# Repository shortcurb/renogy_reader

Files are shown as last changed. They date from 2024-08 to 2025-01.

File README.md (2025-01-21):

Respectfully and appreciably forked from wrybread/ESP32ArduinoRenogy. There's no way I would have been able to figure out the Modbus on my own.

Like wrybread, I have an off-grid need for electricity, mostly because I want to try running a very small homelab in my backyard shed.
I have a Renogy Wanderer 30A charger and a Wanderer 10A charger (generally referenced as CC herein), if I haven't updated this README saying otherwise, they both support the software and hardware in this repo.

This repo contains both a through-hole PCB and an expanded aruidno sketch that reads the data from the CC and fires it off to an MQTT broker
# Hardware features:
* ESP32
* LM2596 through hole variant, from eBay/Amazon 4V-40V input, 5V, 3A output (make sure you set the potentiometer correctly!!)
* two DS18B20 temperature probes (one onboard, one via connector)
* Power connector
* Three connectors for offboard relays (either 5V or powered by the board's main input voltage)
* RJ45 (ethernet) header, its mechanically compatible with an RJ12 cord, which is what you'll need for the CC plug
    * This actually insn't true, as the RJ12 can get inserted wrong and have incorrect contacts. I soldered an ethernet cord to an RJ12 cord and am using that now.

If you want an unpopulated or pre-populated board, please reach out to me. JLCPCB sends me 5 for every order, and I only need 1.

# Software features:
There are multiple pieces of software here:
# renogy_reader_arduino
Reads data from the modbus and the custom PCB and fires it off to an MQTT broker

# renogy_mqtt_db_interface
Is intented to run as a container on a local server (such as a homelab), read data sent from the arduino over MQTT, and write it to a mariadb database

# ESP32ArduinoRenogy

This lets you read data from Renogy charge controllers via their RS232 port using an ESP32 or Arduino. 

Wanderer

The inspiration came when I needed to power a pump at a remote pond whenever there was sufficient power from a solar panel, and I was surprised to learn that the load switch on the Renogy controllers can't do that natively. The load switch is only designed to control lights at night. Silly. This lets me use the load switch to power whatever I want, but see the "Notes on the Load Switch" below for some notes on its limitations. And of course it lets me do whatever else I want with the data from the Renogy charge controller including using a relay, and gives me a dirt cheap way to read the battery voltage, panel voltage and load wattage from an ESP32 or Arduino.

So far I've only tested this with Renogy Wanderer 30A (CTRL-WND30-LI) and Wanderer 10A charge controllers, please post to the Issues section if you test on more and I'll add it to the list below. It *should* work with any Renogy charge controller that has an RS232 port, which I think is all of them since they want to sell their [bluetooth module](https://www.renogy.com/bt-2-bluetooth-module/) that works with the RS232 port.

Here's a pic of my installation:

installation

## Making the Cable

Here's an overall wiring diagram:

wiring diagram

You'll need make a cable to connect the controller to your ESP32 or Arduino. Start with an RJ12 cable, which is an old phone cable with 6 wires. Make sure it doesn't have only 4 wires, which is an RJ11 cable.

Here's the RJ12 jack on my cable, note how there's 6 wires (white, black, red, green, yellow, blue):

rj12 cable jack

I don't know how standard the wire colors are but those are the colors on mine. You need the first 3 wires from the left, which on mine are the white, black and red wire.

You'll also need a TTL to RS232 level adjuster. I used [this one](https://www.amazon.com/dp/B07BJJ3TZR) but there are lots of other options (google "max3232"):

level adjuster

If the listing goes away, it's the "NOYITO TTL to RS232 Module TTL RS232 Mutual Conversion Module", costs $7. See the wiring diagram above for instructions on connecting to it.

## Use

After connecting the cable and flashing your ESP or Arduino you should be seeing data from your charge controller in Serial Monitor:

serial monitor

Feel free to post to Issues if not.

## Notes on the Code

There's a struct that holds all the data from the charge controller. A look at the struct shows what data that is:

```
struct Controller_data {
  
  uint8_t battery_soc;               // percent
  float battery_voltage;             // volts
  float battery_charging_amps;       // amps
  uint8_t battery_temperature;       // celcius
  uint8_t controller_temperature;    // celcius
  float load_voltage;                // volts
  float load_amps;                   // amps
  uint8_t load_watts;                // watts
  float solar_panel_voltage;         // volts
  float solar_panel_amps;            // amps
  uint8_t solar_panel_watts;         // watts
  float min_battery_voltage_today;   // volts
  float max_battery_voltage_today;   // volts
  float max_charging_amps_today;     // amps
  float max_discharging_amps_today;  // amps
  uint8_t max_charge_watts_today;    // watts
  uint8_t max_discharge_watts_today; // watts
  uint8_t charge_amphours_today;     // amp hours
  uint8_t discharge_amphours_today;  // amp hours
  uint8_t charge_watthours_today;    // watt hours
  uint8_t discharge_watthours_today; // watt hours
  uint8_t controller_uptime_days;    // days
  uint8_t total_battery_overcharges; // count
  uint8_t total_battery_fullcharges; // count

  // convenience values
  float battery_temperatureF;        // fahrenheit
  float controller_temperatureF;     // fahrenheit
  float battery_charging_watts;      // watts. necessary? Does it ever differ from solar_panel_watts?
  long last_update_time;             // millis() of last update time
};
Controller_data renogy_data;
```

For example there's battery_soc (battery state of charge), the battery_voltage, the battery_charging_amps, etc. There's examples in the code of how to access them, but for example you get the battery voltage like this:

```
Serial.println( renogy_data.battery_voltage );
```

There's another struct that holds the info about the charge controller (it's voltage rating, amp rating, serial number, etc). I don't think all those are working yet. For example the serial number it reports is different than the one printed on my charge controller, which I think is just because of how my code processes the serial number data, but I don't need that functionality so I haven't fixed that yet. 

And note the commented out section in the code that turns the load switch on and off. For example this would turn the load on for 10 seconds:

```
renogy_control_load(1)
delay(10000);
renogy_control_load(0)
```

## Notes on the Load Switch

I think the load switch uses a MOSFET, which means anything with an inductive kickback (like a brush motor) might damage the switch or the unit itself. But I've been powering a bilge pump on it, which I think is an inductive load, for months without an issue. I'm willing to risk my cheapie PWM charge controller for that, but be careful what you power from the load switch directly. And of course you can connect a relay to the load switch to control anything else, or just connect a relay directly to your Arduino or ESP32.

Renogy is oddly uncommunicative about the limits of the load switch, and my theory is that that's because it's a bit complicated. My theory is that the capacity is shared between the battery input and the switch output. So for example if the 10 amp charge controller is pulling 8 amps of power from the solar panels, that leaves only 2 amps for the load switch. That would explain both why they don't mention the actual load limit, and why they only let us control the load at night (when the solar panels aren't competing for the capacity). But still, if that's the case, it would be nice for Renogy to mention that. And furthermore having options to control the load switch in the day would allow for someone to either have a larger controller than their panel so daytime power wouldn't be an issue, or to just use a relay connected to the load switch. Furthermore the manual says the controller will shut off the load switch and show an error code if the capacity reaches 105%, so maybe exceeding the load limit by a bit isn't catastrophic.

Anyway you can of course bypass all these issues by just controlling a relay directly from your ESP or Arduino.

For the record here's a screenshot from the Renogy Wanderer 10a manual showing the modes of the load switch:

load modes

Such an odd limitation to design them only to handle lights. Oh well, nothing an ESP32 or Arduino can't fix.

## General Notes

- as of now this is untested on an Arduino, I've only used it with ESP32's (both a Rover and a Wroom). It should work fine with an Arduino, the only thing I'm uncertain about is whether you can have two Serial interfaces with all Arduinos (and this script uses one Serial interface for communication with the Renogy controller and one to print status to the console). It should work fine though. If you test with an Arduino please post to this project's Issues section.

- I couldn't power the ESP32 directly from the charge controller, my theory is that it's so low power that the charge controller thinks nothing is connected and shuts off the USB port. Oh well, I used one of [these](https://www.amazon.com/gp/product/B08H89LTP5) 12v to 5v adaptors:

12v to 5v

## See Also

There's a couple of other projects that get data from the Renogy charge controllers. Oddly I couldn't find anything that uses an ESP32 or Arduino though.

- [here's a NodeJS project](https://github.com/mickwheelz/NodeRenogy)

- [here's a pure javascript project](https://github.com/menloparkinnovation/renogy-rover)

Much thanks to them! They made this much easier. 

Those are all for Raspberry Pi's or similar though. For my use case a Raspberry Pi is vastly overkill and has a lot of drawbacks: it needs to be shutdown properly, has a corruptible SD card, uses about 10 times the power of an Arduino or ESP (and an ESP32 can use deep sleep mode, which uses almost no power at all), has a super slow bootup time as opposed to instantly on, has an OS which needs to be kept up to date and is subject to lock ups, etc. ESP32's are in general much more robust in my experience. Once you get it working it just works, I'm betting for decades. That's not to say there aren't times where a Pi or similar makes more sense of course, but a remote solar installation probably isn't one of them.

I also attached Renogy's RS232/modbus manual, it's somewhat occaisonally helpful if you squint at it long enough.

## Tested On

So far it's been tested and confirmed working well on these controllers:

- Wanderer 30A (CTRL-WND30-LI)
- Wanderer 10A

It *should* work on any Renogy charge controller with an RS232 port. And most if not all of them have that port since Renogy wants to sell their [bluetooth module](https://www.renogy.com/bt-2-bluetooth-module/), which uses that port to get its data. This should also be pretty easy to adapt to other charge controllers that make their data available via modbus.
 
Please post to the Issues section if you test on other Renogy charge controllers, or email me (wrybread@gmail.com). 

## To Do

- I don't think it's correctly reading the serial number register, and possibly some of the other registers having to do with the model number. Please let me know if you figure out any fixes. (wrybread@gmail.com or post to Issues).

- would be nice to add Bluetooth support for monitoring from a phone, posting to MQTT brokers and pvwatts, etc.

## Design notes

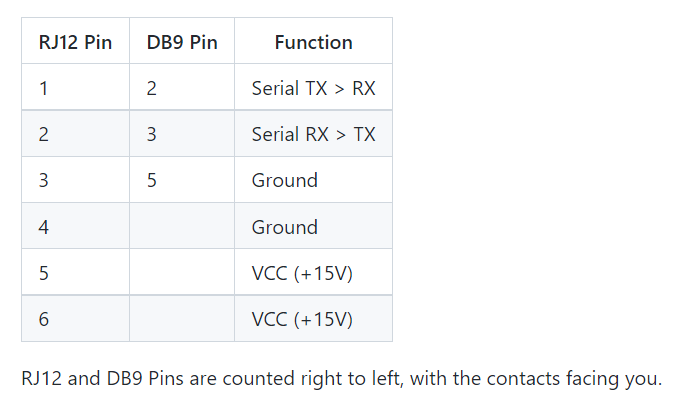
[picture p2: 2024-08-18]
references/5f45364e8110b863d892ca47645f56b64de6c801.png

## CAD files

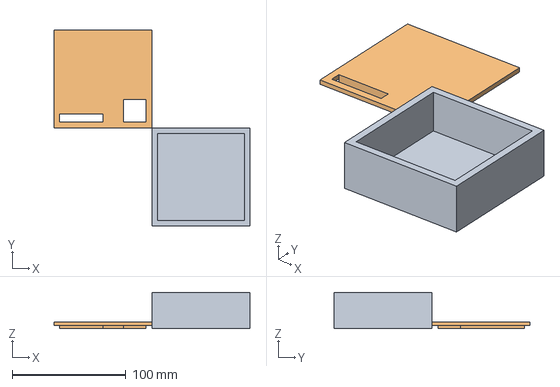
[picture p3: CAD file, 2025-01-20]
printed_case/renogy_reader_case.FCStd
172.0 x 172.0 x 32.0 mm
Container
Lid

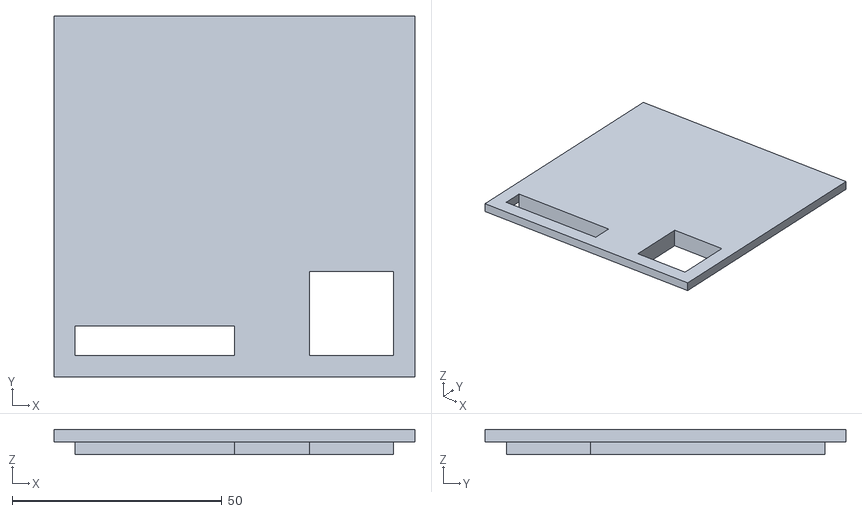
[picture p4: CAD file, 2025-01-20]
printed_case/lid.stl
86.0 x 86.0 x 6.00

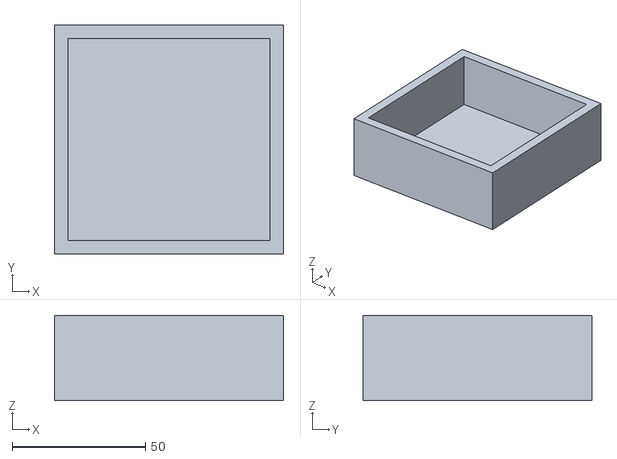
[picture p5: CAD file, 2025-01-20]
printed_case/container.stl
86.0 x 86.0 x 32.0

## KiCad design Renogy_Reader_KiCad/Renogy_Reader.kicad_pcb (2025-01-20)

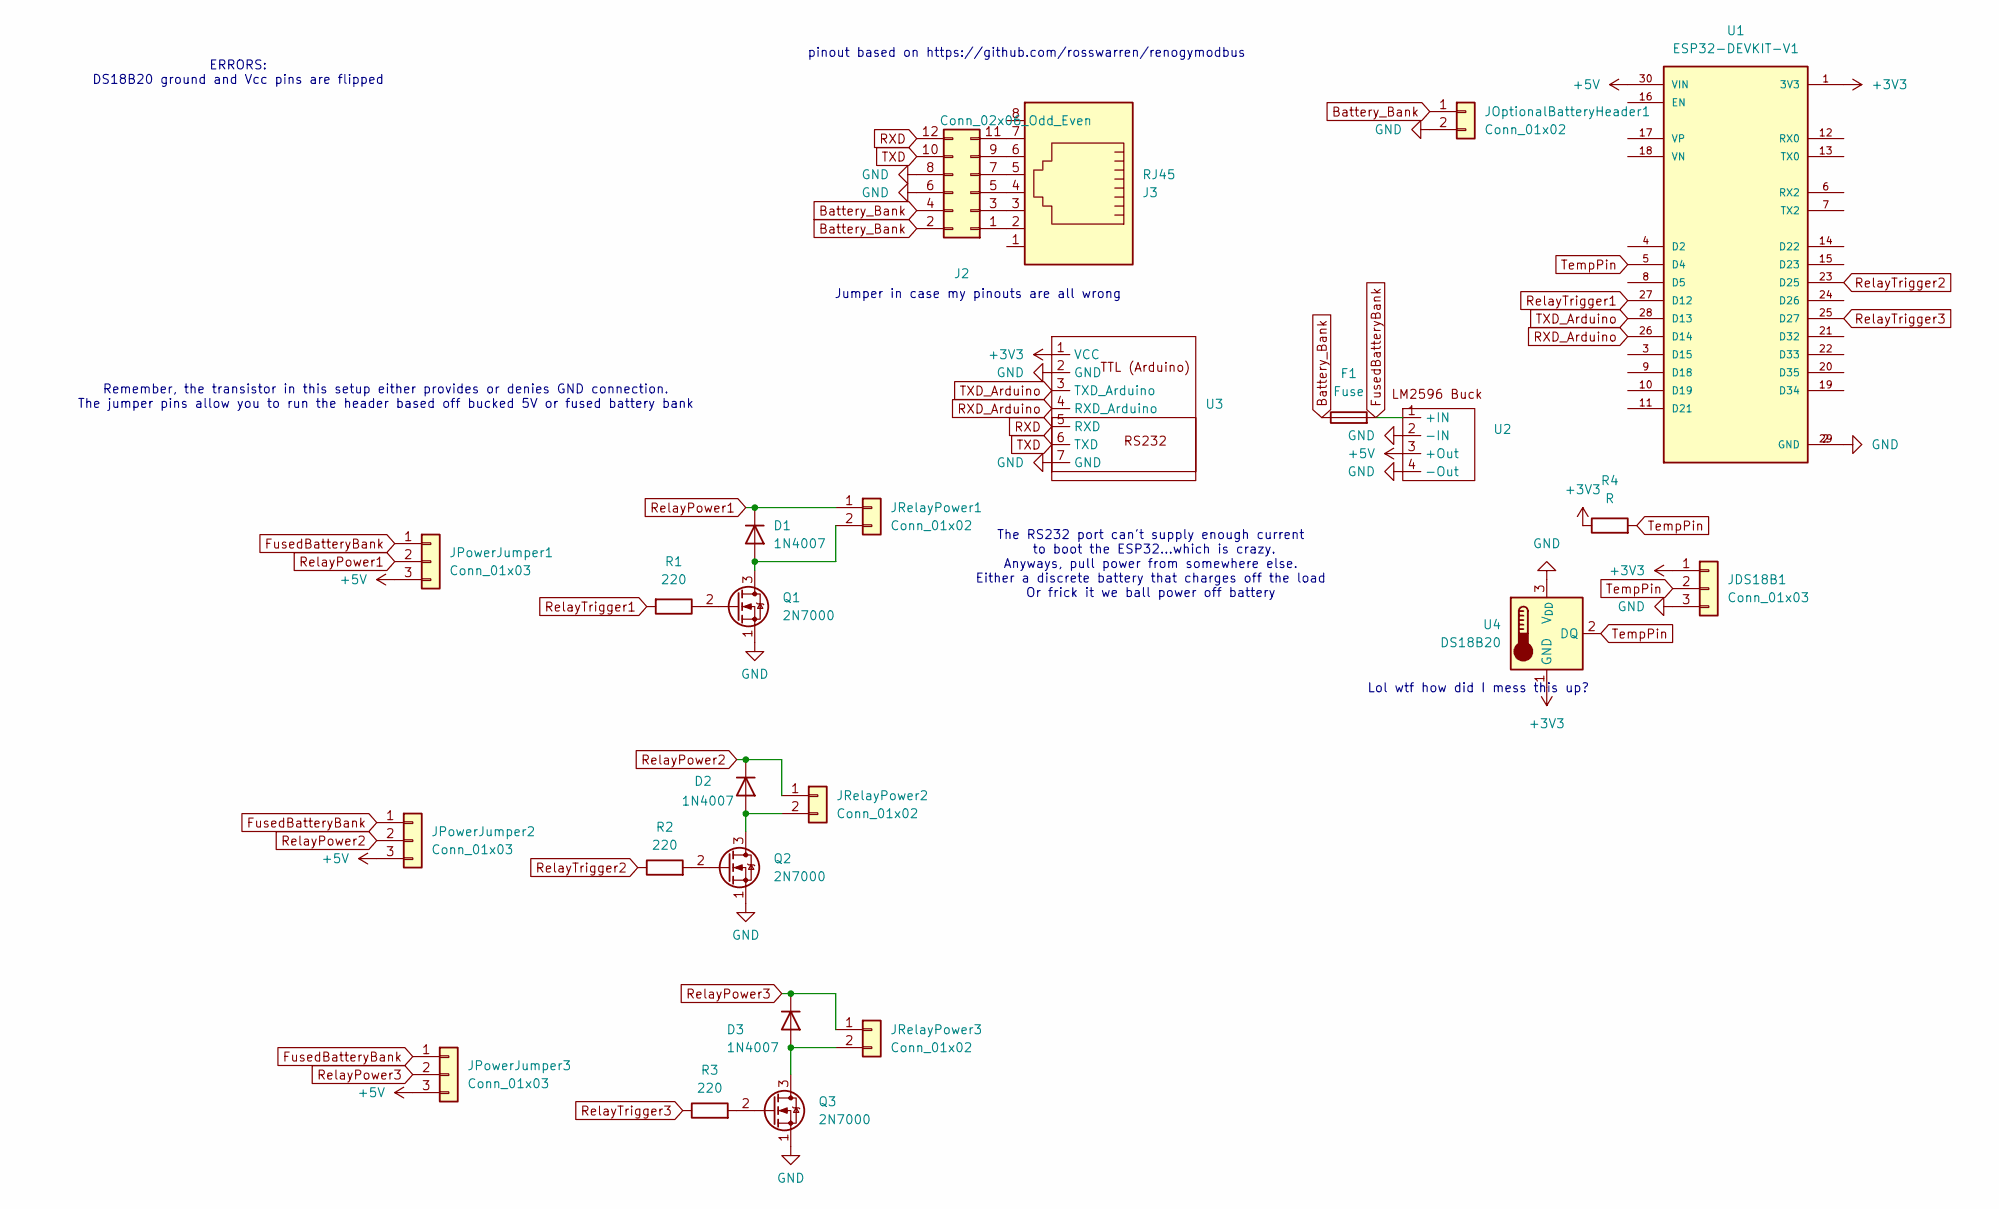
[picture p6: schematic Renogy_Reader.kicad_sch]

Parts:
D1, D2, D3: 1N4007; D_DO-41_SOD81_P10.16mm_Horizontal
F1: Fuse; Fuseholder_Clip-5x20mm_Keystone_3512P_Inline_P23.62x7.27mm_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
J2: Conn_02x06_Odd_Even; PinHeader_2x06_P2.54mm_Vertical
J3: RJ45; RJ45_Amphenol_54602-x08_Horizontal
JDS18B1: Conn_01x03; JST_EH_B3B-EH-A_1x03_P2.50mm_Vertical
JOptionalBatteryHeader1: Conn_01x02; JST_EH_B2B-EH-A_1x02_P2.50mm_Vertical
JPowerJumper1, JPowerJumper2, JPowerJumper3: Conn_01x03; JST_EH_B3B-EH-A_1x03_P2.50mm_Vertical
JRelayPower1, JRelayPower2, JRelayPower3: Conn_01x02; JST_EH_B2B-EH-A_1x02_P2.50mm_Vertical
Q1, Q2, Q3: 2N7000; TO-92_Inline
R1, R2, R3: 220; R_Axial_DIN0411_L9.9mm_D3.6mm_P12.70mm_Horizontal
R4: R; R_Axial_DIN0411_L9.9mm_D3.6mm_P12.70mm_Horizontal
U1: ESP32-DEVKIT-V1; MODULE_ESP32_DEVKIT_V1; PARTREV N/A
U2: LM2596-AE
U3: TTL-RS232 Converter
U4: DS18B20; TO-92_Inline

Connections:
+3V3: JDS18B1.1, R4.1, U1.1 (3V3), U3.1 (VCC), U4.1 (GND)
+5V: JPowerJumper1.3, JPowerJumper2.3, JPowerJumper3.3, U1.30 (VIN), U2.3 (+Out)
Battery_Bank: F1.1, J2.2, J2.4, JOptionalBatteryHeader1.1
FusedBatteryBank: F1.2, JPowerJumper1.1, JPowerJumper2.1, JPowerJumper3.1, U2.1 (+IN)
GND: J2.6, J2.8, JDS18B1.3, JOptionalBatteryHeader1.2, Q1.1 (S), Q2.1 (S), Q3.1 (S), U1.2 (GND), U1.29 (GND), U2.2 (-IN), U2.4 (-Out), U3.2 (GND), U3.7 (GND), U4.3 (V_{DD})
unnamed: D1.2 (A), JRelayPower1.2, Q1.3 (D)
unnamed: D2.2 (A), JRelayPower2.2, Q2.3 (D)
unnamed: D3.2 (A), JRelayPower3.2, Q3.3 (D)
unnamed: J2.1, J3.2
unnamed: J2.3, J3.3
unnamed: J2.5, J3.4
unnamed: J2.7, J3.5
unnamed: J2.9, J3.6
unnamed: J2.11, J3.7
unnamed: Q1.2 (G), R1.1
unnamed: Q2.2 (G), R2.2
unnamed: Q3.2 (G), R3.2
RXD: J2.12, U3.5 (RXD)
RXD_Arduino: U1.26 (D14), U3.4 (RXD_Arduino)
RelayPower1: D1.1 (K), JPowerJumper1.2, JRelayPower1.1
RelayPower2: D2.1 (K), JPowerJumper2.2, JRelayPower2.1
RelayPower3: D3.1 (K), JPowerJumper3.2, JRelayPower3.1
RelayTrigger1: R1.2, U1.27 (D12)
RelayTrigger2: R2.1, U1.23 (D25)
RelayTrigger3: R3.1, U1.25 (D27)
TXD: J2.10, U3.6 (TXD)
TXD_Arduino: U1.28 (D13), U3.3 (TXD_Arduino)
TempPin: JDS18B1.2, R4.2, U1.5 (D4), U4.2 (DQ)

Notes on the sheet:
Lol wtf how did I mess this up?
The RS232 port can't supply enough current to boot the ESP32...which is crazy. Anyways, pull power from somewhere else. Either a discrete battery that charges off the load Or frick it we ball power off battery
Remember, the transistor in this setup either provides or denies GND connection. The jumper pins allow you to run the header based off bucked 5V or fused battery bank
Jumper in case my pinouts are all wrong
ERRORS: DS18B20 ground and Vcc pins are flipped
pinout based on https://github.com/rosswarren/renogymodbus

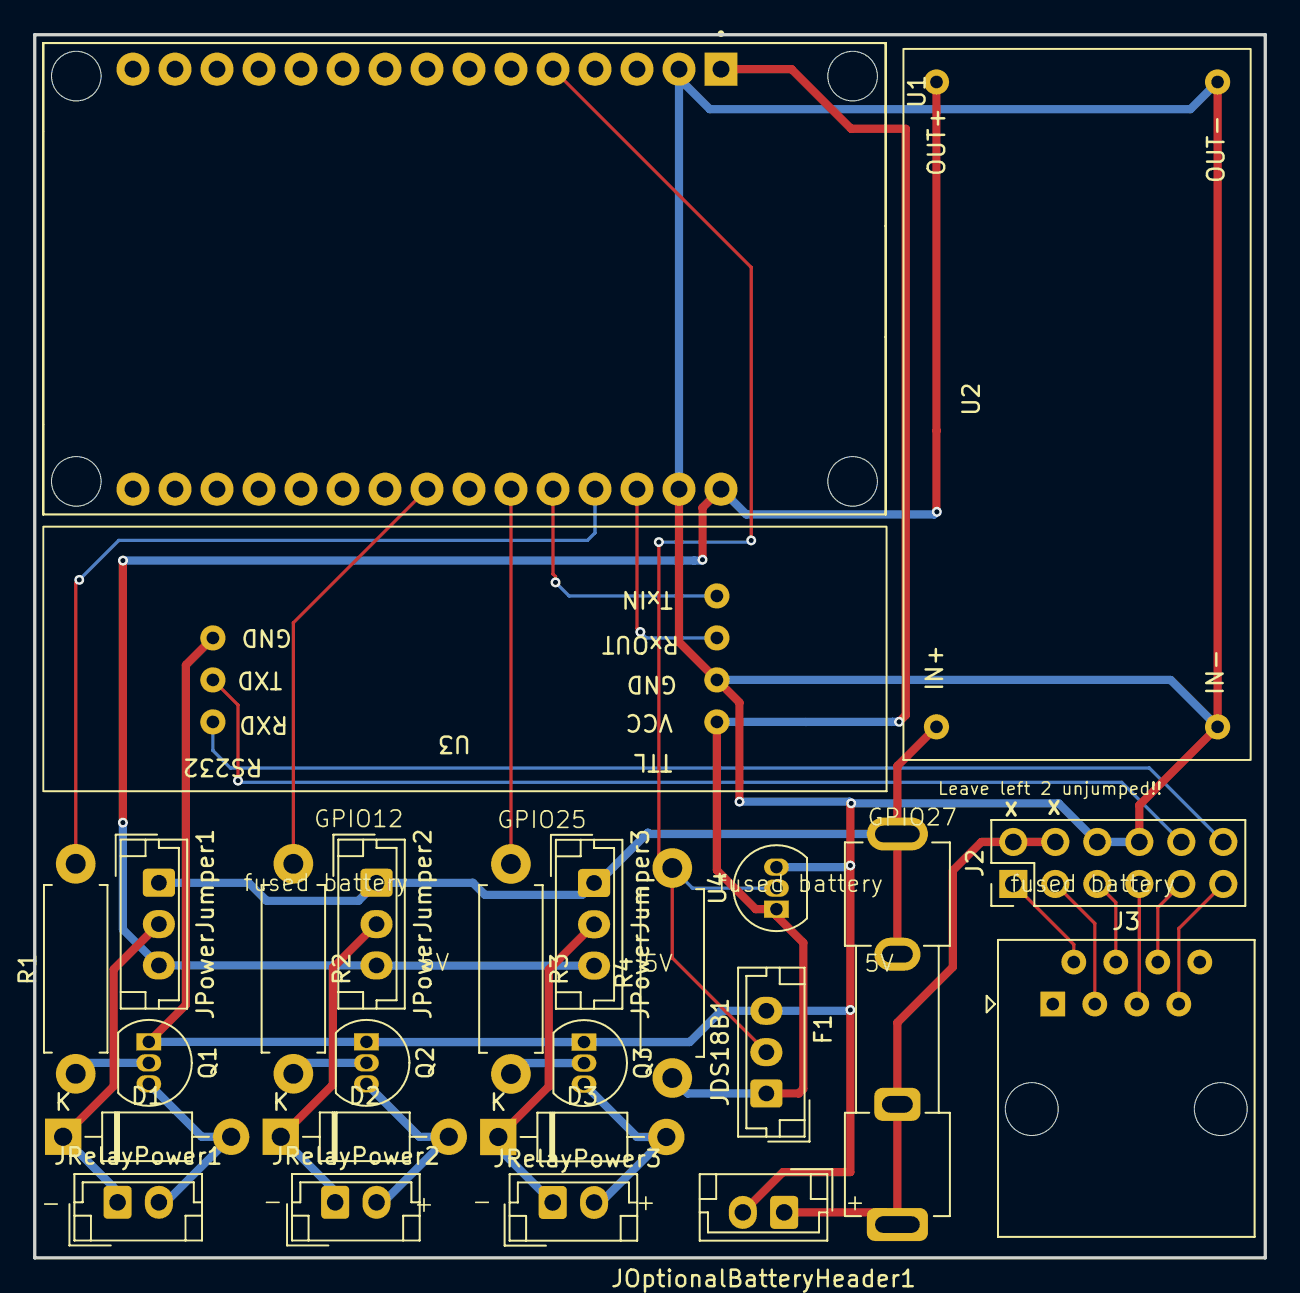
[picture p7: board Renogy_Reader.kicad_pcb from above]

Board: 2 copper layers, 74.4 x 74.0 mm, 25 parts (0 on the bottom side), 28 nets.

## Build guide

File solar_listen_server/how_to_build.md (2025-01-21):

sudo docker build -t solar-listen .
sudo docker run --env-file docker.env --name solar-listen -d solar-listen
The open portainer, switch the new container's network to bombur_default, and it'll run

If you get "key not found" errors, it just means that the ESP32 is sending MQTTs
that solar_listen.py doesn't know whether to treat as a string or a float. 
Make an entry in         self.data_structure = { if you want the error to go away

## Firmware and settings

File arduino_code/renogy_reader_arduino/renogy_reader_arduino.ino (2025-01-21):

// https://github.com/wrybread/ESP32ArduinoRenogy
// https://github.com/syvic/ModbusMaster
#include <ModbusMaster.h>
#include "secrets.h"
#include <WiFi.h>
#include <PubSubClient.h>
#include <ArduinoJson.h>  // Include ArduinoJson library
#include "esp_task_wdt.h" // Watchdog timer
#include <OneWire.h>
#include <DallasTemperature.h>

ModbusMaster node;

const int relaypin1 = 12;  // Relay 1 connected to D12
const int relaypin2 = 25;  // Relay 2 connected to D25
const int relaypin3 = 27;  // Relay 3 connected to D27 

#define RXD2 13
#define TXD2 14
#define ONE_WIRE_BUS 4  // GPIO D4 on ESP32

OneWire oneWire(ONE_WIRE_BUS);
DallasTemperature sensors(&oneWire);

const uint32_t num_data_registers = 35;
const uint32_t num_info_registers = 17;

bool simulator_mode = false;

WiFiClient espClient;
PubSubClient client(espClient);
const char* commandtopic = "kili/sagehouse/solar/renogy20/command";
int modbus_timeout_count = 0;  // Count consecutive Modbus timeouts
const int max_modbus_timeout_count = 5;  // Reset if this threshold is exceeded

struct Controller_data {
  
  uint8_t battery_soc;               // percent
  float battery_voltage;             // volts
  float battery_charging_amps;       // amps
  int16_t battery_temperature;       // celcius
  int16_t controller_temperature;    // celcius
  float load_voltage;                // volts
  float load_amps;                   // amps
  uint8_t load_watts;                // watts
  float solar_panel_voltage;         // volts
  float solar_panel_amps;            // amps
  uint8_t solar_panel_watts;         // watts
  float min_battery_voltage_today;   // volts
  float max_battery_voltage_today;   // volts
  float max_charging_amps_today;     // amps
  float max_discharging_amps_today;  // amps
  uint8_t max_charge_watts_today;    // watts
  uint8_t max_discharge_watts_today; // watts
  uint8_t charge_amphours_today;     // amp hours
  uint8_t discharge_amphours_today;  // amp hours
  uint8_t charge_watthours_today;    // watt hours
  uint8_t discharge_watthours_today; // watt hours
  uint8_t controller_uptime_days;    // days
  uint8_t total_battery_overcharges; // count
  uint8_t total_battery_fullcharges; // count
  uint16_t raw_data;

  // convenience values
  float battery_temperatureF;        // fahrenheit
  float controller_temperatureF;     // fahrenheit
  float battery_charging_watts;      // watts. necessary? Does it ever differ from solar_panel_watts?
  long last_update_time;             // millis() of last update time
  bool controller_connected;         // bool if we successfully read data from the controller
  float ds18tempC;
  float ds18tempF;
};
Controller_data renogy_data;

struct Controller_info {
  
  uint8_t voltage_rating;            // volts
  uint8_t amp_rating;                // amps
  uint8_t discharge_amp_rating;      // amps
  uint8_t type;
  uint8_t controller_name;
  char software_version[40];
  char hardware_version[40];
  char serial_number[40];
  uint8_t modbus_address;  

  float wattage_rating;
  long last_update_time;           // millis() of last update time
};
Controller_info renogy_info;

struct Relay_info {
    int relay1state;
    int relay2state;
    int relay3state;
    int loadstate;
};
Relay_info relay_info;

struct Board_info {
    float boardTempC;
    float boardTempF;
};
Board_info board_info;

void callback(char* topic, byte* message, unsigned int length) {
  Serial.print("Message arrived on topic: ");
  Serial.print(topic);
  Serial.print(". Message: ");
  String messageTemp;

  for (int i = 0; i < length; i++) {
    Serial.print((char)message[i]);
    messageTemp += (char)message[i];
  }
  Serial.println();

  // Handle the message received
  if (String(topic) == commandtopic) {
    handle_command(messageTemp);

  }
}

// control the load pins on Renogy charge controllers that have them
void renogy_control_load(bool state) {
    if (state==1) {
        Serial.println("Turning load on");
        node.writeSingleRegister(0x010A, 1);  // turn on load
    }
    else {
        Serial.println("Turning load off");
        node.writeSingleRegister(0x010A, 0);  // turn off load
    }
}

void reconnect() {
    while (!client.connected()) {
        Serial.print("Attempting MQTT connection...");
        if (WiFi.status() != WL_CONNECTED) { // Check Wi-Fi status first
            setup_wifi();
        }
        if (client.connect("ESP32Client", mqtt_user, mqtt_password)) {
            Serial.println("connected");
            client.subscribe(commandtopic);
        } else {
            Serial.print("failed, rc=");
            Serial.print(client.state());
            Serial.println(" try again in 5 seconds");
            delay(5000);
        }
    }
}

void setup_wifi() {
    delay(10);
    Serial.print("Connecting to ");
    WiFi.begin(ssid, password);
    while (WiFi.status() != WL_CONNECTED) {
        delay(500);
        Serial.print(".");
    }
    Serial.println("WiFi connected");
    Serial.println("IP address: ");
    Serial.println(WiFi.localIP());
}

void handle_command(const String message) {
    pinMode(relaypin1, OUTPUT);
    pinMode(relaypin2, OUTPUT);
    pinMode(relaypin3, OUTPUT);

    // Debug print
    Serial.println("Handling message: " + message);

    // Matching commands to control relays
    if (message == "relay1 on") {
        digitalWrite(relaypin1, HIGH);
    } else if (message == "relay1 off") {
        digitalWrite(relaypin1, LOW);
    } else if (message == "relay2 on") {
        digitalWrite(relaypin2, HIGH);
    } else if (message == "relay2 off") {
        digitalWrite(relaypin2, LOW);
    } else if (message == "relay3 on") {
        digitalWrite(relaypin3, HIGH);
    } else if (message == "relay3 off") {
        digitalWrite(relaypin3, LOW);
    } else if (message == "load on") {
        renogy_control_load(1);
    } else if (message == "load off") {
        renogy_control_load(0);
    } else {
        Serial.println("Unknown command: " + message);
    }
}

void setup() {
    Serial.begin(115200);
    Serial.println("Started!");

    // Configure and initialize the Task Watchdog Timer (WDT)
    static bool wdt_initialized = false;
    if (!wdt_initialized) {
        esp_task_wdt_config_t wdt_config = {
            .timeout_ms = 10000,       // Set WDT timeout to 10,000 ms
            .trigger_panic = true      // Trigger panic on timeout
        };
        esp_task_wdt_init(&wdt_config); // Initialize WDT with the config
        esp_task_wdt_add(NULL);         // Add current task to the watchdog
        wdt_initialized = true;         // Mark as initialized to avoid reinitializing
    }

    Serial2.begin(9600, SERIAL_8N1, RXD2, TXD2); 
    int modbus_address = 255; 
    node.begin(modbus_address, Serial2); 

    setup_wifi();
    client.setServer(mqtt_server, mqtt_port);
    client.setCallback(callback);
    sensors.begin();

    delay(100);
}

void loop() {
    esp_task_wdt_reset();  // Initial reset at the start of loop

    if (WiFi.status() != WL_CONNECTED) {  // Check Wi-Fi connection
        setup_wifi();
        esp_task_wdt_reset();  // Reset after Wi-Fi reconnection attempt
    }

    if (!client.connected()) {
        reconnect();
        esp_task_wdt_reset();  // Reset after MQTT reconnection attempt
    }

    client.loop();
    esp_task_wdt_reset();  // Reset after processing client.loop()

    static uint32_t lastTaskTime = 0;  
    const uint32_t TASK_INTERVAL = 5000;  // 5-second interval

    if (millis() - lastTaskTime >= TASK_INTERVAL) {
        lastTaskTime = millis();
        send_data();           // Publish data and perform tasks
        esp_task_wdt_reset();  // Reset watchdog timer after successful task
    }

    delay(10);  // Small delay to prevent a tight loop; adjust if needed
}

void send_data() {
    static uint32_t i;
    i++;

    // set word 0 of TX buffer to least-significant word of counter (bits 15..0)
    node.setTransmitBuffer(0, lowWord(i));  
    // set word 1 of TX buffer to most-significant word of counter (bits 31..16)
    node.setTransmitBuffer(1, highWord(i));

    if (renogy_read_data_registers() && renogy_read_info_registers()) {
        read_relay_state();
        read_ds18b20();
        modbus_timeout_count = 0;  // Reset timeout count on successful read

        client.publish("kili/sagehouse/solar/renogy20/raw_data", String(renogy_data.raw_data).c_str());
        client.publish("kili/sagehouse/solar/renogy20/board_temperature", String(board_info.boardTempC).c_str());
        client.publish("kili/sagehouse/solar/renogy20/board_temperatureF", String(board_info.boardTempF).c_str());
        client.publish("kili/sagehouse/solar/renogy20/status", "Charge controller connected");
        client.publish("kili/sagehouse/solar/renogy20/battery_soc", String(renogy_data.battery_soc).c_str());
        client.publish("kili/sagehouse/solar/renogy20/battery_voltage", String(renogy_data.battery_voltage).c_str());
        client.publish("kili/sagehouse/solar/renogy20/battery_charging_amps", String(renogy_data.battery_charging_amps/10).c_str());
        client.publish("kili/sagehouse/solar/renogy20/battery_temperature", String(renogy_data.battery_temperature).c_str());
        client.publish("kili/sagehouse/solar/renogy20/controller_temperature", String(renogy_data.controller_temperature).c_str());
        client.publish("kili/sagehouse/solar/renogy20/load_voltage", String(renogy_data.load_voltage).c_str());
        client.publish("kili/sagehouse/solar/renogy20/load_amps", String(renogy_data.load_amps).c_str());
        client.publish("kili/sagehouse/solar/renogy20/load_watts", String(renogy_data.load_watts).c_str());
        client.publish("kili/sagehouse/solar/renogy20/solar_panel_voltage", String(renogy_data.solar_panel_voltage).c_str());
        client.publish("kili/sagehouse/solar/renogy20/solar_panel_amps", String(renogy_data.solar_panel_amps).c_str());
        client.publish("kili/sagehouse/solar/renogy20/solar_panel_watts", String(renogy_data.solar_panel_watts).c_str());
        client.publish("kili/sagehouse/solar/renogy20/min_battery_voltage_today", String(renogy_data.min_battery_voltage_today).c_str());
        client.publish("kili/sagehouse/solar/renogy20/max_battery_voltage_today", String(renogy_data.max_battery_voltage_today).c_str());
        client.publish("kili/sagehouse/solar/renogy20/max_charging_amps_today", String(renogy_data.max_charging_amps_today).c_str());
        client.publish("kili/sagehouse/solar/renogy20/max_discharging_amps_today", String(renogy_data.max_discharging_amps_today).c_str());
        client.publish("kili/sagehouse/solar/renogy20/max_charge_watts_today", String(renogy_data.max_charge_watts_today).c_str());
        client.publish("kili/sagehouse/solar/renogy20/max_discharge_watts_today", String(renogy_data.max_discharge_watts_today).c_str());
        client.publish("kili/sagehouse/solar/renogy20/charge_amphours_today", String(renogy_data.charge_amphours_today).c_str());
        client.publish("kili/sagehouse/solar/renogy20/discharge_amphours_today", String(renogy_data.discharge_amphours_today).c_str());
        client.publish("kili/sagehouse/solar/renogy20/charge_watthours_today", String(renogy_data.charge_watthours_today).c_str());
        client.publish("kili/sagehouse/solar/renogy20/discharge_watthours_today", String(renogy_data.discharge_watthours_today).c_str());
        client.publish("kili/sagehouse/solar/renogy20/controller_uptime_days", String(renogy_data.controller_uptime_days).c_str());
        client.publish("kili/sagehouse/solar/renogy20/total_battery_overcharges", String(renogy_data.total_battery_overcharges).c_str());
        client.publish("kili/sagehouse/solar/renogy20/total_battery_fullcharges", String(renogy_data.total_battery_fullcharges).c_str());
        client.publish("kili/sagehouse/solar/renogy20/battery_temperatureF", String(renogy_data.battery_temperatureF).c_str());
        client.publish("kili/sagehouse/solar/renogy20/controller_temperatureF", String(renogy_data.controller_temperatureF).c_str());
        client.publish("kili/sagehouse/solar/renogy20/battery_charging_watts", String(renogy_data.battery_charging_watts/10).c_str());
        client.publish("kili/sagehouse/solar/renogy20/last_update_time", String(renogy_data.last_update_time).c_str());
        client.publish("kili/sagehouse/solar/renogy20/controller_connected", renogy_data.controller_connected ? "true" : "false");

        client.publish("kili/sagehouse/solar/renogy20/voltage_rating", String(renogy_info.voltage_rating).c_str());
        client.publish("kili/sagehouse/solar/renogy20/amp_rating", String(renogy_info.amp_rating).c_str());
        client.publish("kili/sagehouse/solar/renogy20/discharge_amp_rating", String(renogy_info.discharge_amp_rating).c_str());
        client.publish("kili/sagehouse/solar/renogy20/type", String(renogy_info.type).c_str());
        client.publish("kili/sagehouse/solar/renogy20/controller_name", String(renogy_info.controller_name).c_str());
        client.publish("kili/sagehouse/solar/renogy20/software_version", renogy_info.software_version);
        client.publish("kili/sagehouse/solar/renogy20/hardware_version", renogy_info.hardware_version);
        client.publish("kili/sagehouse/solar/renogy20/serial_number", renogy_info.serial_number);
        client.publish("kili/sagehouse/solar/renogy20/modbus_address", String(renogy_info.modbus_address).c_str());
        client.publish("kili/sagehouse/solar/renogy20/wattage_rating", String(renogy_info.wattage_rating).c_str());
        client.publish("kili/sagehouse/solar/renogy20/last_update_time", String(renogy_info.last_update_time).c_str());

        client.publish("kili/sagehouse/solar/renogy20/relay1state", String(relay_info.relay1state).c_str());
        client.publish("kili/sagehouse/solar/renogy20/relay2state", String(relay_info.relay2state).c_str());
        client.publish("kili/sagehouse/solar/renogy20/relay3state", String(relay_info.relay3state).c_str());
        client.publish("kili/sagehouse/solar/renogy20/loadstate", String(relay_info.loadstate).c_str());


        esp_task_wdt_reset();  // Reset WDT after publishing data

    } else {
        client.publish("kili/sagehouse/solar/renogy20/status", "Charge controller disconnected");
        modbus_timeout_count++;
        if (modbus_timeout_count >= max_modbus_timeout_count) {
            esp_task_wdt_reset();  // Reset WDT after publishing data
            ESP.restart();  // Restart if too many consecutive timeouts
        }

    }
}

bool renogy_read_data_registers() {
  uint8_t j, result;
  uint16_t data_registers[num_data_registers];
  char buffer1[40], buffer2[40];
  uint16_t raw_data;

  // Prints data about each read to the console
  bool print_data = false;

  result = node.readHoldingRegisters(0x100, num_data_registers);
  if (result == node.ku8MBSuccess) {
    if (print_data) Serial.println("Successfully read the data registers!");
    renogy_data.controller_connected = true;

    for (j = 0; j < num_data_registers; j++) {
      data_registers[j] = node.getResponseBuffer(j);
      if (print_data) Serial.println(data_registers[j]);
    }

    renogy_data.battery_soc = data_registers[0];
    renogy_data.battery_voltage = data_registers[1] * 0.1; // Will it crash if data_registers[1] doesn't exist?
    renogy_data.battery_charging_amps = data_registers[2] * 0.1;
    renogy_data.battery_charging_watts = renogy_data.battery_voltage * renogy_data.battery_charging_amps;

    // ✅ Read and decode temperatures from 0x103 (data_registers[3])
    raw_data = data_registers[3];  // Example: 0x8C7C (35980)

    // Extract battery temperature (7 bits)
    int8_t battery_temperature = raw_data & 0x7F;
    // Extract battery temperature sign (bit 7)
    if (raw_data & 0x80) battery_temperature = -battery_temperature;

    // Extract controller temperature (7 bits)
    int8_t controller_temperature = (raw_data >> 8) & 0x7F;
    // Extract controller temperature sign (bit 15)
    if (raw_data & 0x8000) controller_temperature = -controller_temperature;

    // Store temperatures in renogy_data struct
    renogy_data.controller_temperature = controller_temperature;
    renogy_data.battery_temperature = battery_temperature;
    renogy_data.raw_data = raw_data;

    // ✅ Fahrenheit conversion
    renogy_data.controller_temperatureF = (renogy_data.controller_temperature * 1.8) + 32;
    renogy_data.battery_temperatureF = (renogy_data.battery_temperature * 1.8) + 32;

    // ✅ Debug print
    if (print_data) {
      Serial.print("Raw Modbus Data (0x103): ");
      Serial.println(raw_data, HEX);
      Serial.print("Controller Temp (C): ");
      Serial.println(renogy_data.controller_temperature);
      Serial.print("Battery Temp (C): ");
      Serial.println(renogy_data.battery_temperature);
    }

    renogy_data.load_voltage = data_registers[4] * 0.1;
    renogy_data.load_amps = data_registers[5] * 0.01;
    renogy_data.load_watts = data_registers[6];
    renogy_data.solar_panel_voltage = data_registers[7] * 0.1;
    renogy_data.solar_panel_amps = data_registers[8] * 0.01;
    renogy_data.solar_panel_watts = data_registers[9];

    renogy_data.min_battery_voltage_today = data_registers[11] * 0.1;
    renogy_data.max_battery_voltage_today = data_registers[12] * 0.1;
    renogy_data.max_charging_amps_today = data_registers[13] * 0.01;
    renogy_data.max_discharging_amps_today = data_registers[14] * 0.1;
    renogy_data.max_charge_watts_today = data_registers[15];
    renogy_data.max_discharge_watts_today = data_registers[16];
    renogy_data.charge_amphours_today = data_registers[17];
    renogy_data.discharge_amphours_today = data_registers[18];
    renogy_data.charge_watthours_today = data_registers[19];
    renogy_data.discharge_watthours_today = data_registers[20];
    renogy_data.controller_uptime_days = data_registers[21];
    renogy_data.total_battery_overcharges = data_registers[22];
    renogy_data.total_battery_fullcharges = data_registers[23];

    renogy_data.last_update_time = millis();

    if (print_data) Serial.println("---");
    return true;
  } 
  else {
    if (result == 0xE2) {
      Serial.println("Timed out reading the data registers!");
    } 
    else {
      Serial.print("Failed to read the data registers... ");
      Serial.println(result, HEX); // E2 is timeout
    }

    // Reset values if the reading fails
    renogy_data.controller_connected = false;
    renogy_data.battery_voltage = 0;
    renogy_data.battery_charging_amps = 0;
    renogy_data.battery_soc = 0;
    renogy_data.battery_charging_amps = 0;
    renogy_data.controller_temperature = 0;
    renogy_data.battery_temperature = 0;
    renogy_data.solar_panel_amps = 0;
    renogy_data.solar_panel_watts = 0;
    renogy_data.battery_charging_watts = 0;
    renogy_data.controller_connected = false;
    return false;
  }
}
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

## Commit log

2024-08-18 Initial upload
    First upload since the forking
    Added KiCad project
    Added info to the readme
    Separated out sensitive info from the Arduino code into a secrets.h (not uploaded)
    [Renogy_Reader.kicad_pcb, Renogy_Reader.kicad_sch]
2024-10-28 update
    has re-try logic for MQTT and wifi connections, and MQTT message if the charge controller isn't connected
2025-01-20 fix temp
    change temps from uint8 to int16 to handle negatives
    [renogy_reader_arduino.ino]
2025-01-20 added 3dprinted case
    [container.stl, lid.stl, renogy_reader_case.FCStd]
2025-01-20 added ds18b20 reading
    and fixed controller and battery temp reading
    [Renogy_Reader.kicad_sch]
2025-01-20 updated kicad
    Updated kicad to show errors in DS18B20 pins
    [Renogy_Reader.kicad_pcb, Renogy_Reader.kicad_sch]
2025-01-21 Change listener
    To handle board_temperature
2025-01-21 Truly fixed
    Fixed the controller temperature problem with chatGPT's help
    [renogy_reader_arduino.ino]
